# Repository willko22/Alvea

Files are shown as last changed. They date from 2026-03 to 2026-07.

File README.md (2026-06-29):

# ⬡ Alvea

**Wireless split keyboard · nRF52840 · ZMK · hexagonal keycaps**

A low-power, battery-powered wireless split keyboard. Each half is a fully independent BLE device with its own battery, per-key LEDs, and USB-C charging.






> [!WARNING]
> **Work in progress — nothing here has been fabricated or tested yet.**
> The hardware is fully designed, but the boards haven't been manufactured, assembled, or brought up. Any performance numbers are design targets, not measurements, and the firmware doesn't exist yet. This repo is documentation of my hobby build, not a guide for replicating it.

---

## 🗺️ Roadmap

| Stage | Status |
|---|---|
| Schematic design | ✅ Done |
| PCB layout | ✅ Done |
| BOM finalized | ✅ Done |
| **PCB polishing + panelization** | 🔄 **In progress** |
| PCB fabrication (JLCPCB) | ⬜ Planned |
| SMT assembly | ⬜ Planned |
| Hand-soldering (sockets, LEDs, battery lead) | ⬜ Planned |
| Bootloader flashing (SWD, one-time) | ⬜ Planned |
| ZMK firmware (keymap + board definition) | ⬜ Not started |
| Bring-up & testing | ⬜ Planned |
| 3D-printed case | ⬜ Planned (after electronics work) |
| Renders / photos | ⬜ Not yet available |

**Right now:** finishing the PCBs and panelizing for fabrication.
**After that:** fabrication → SMT assembly → hand-soldering → firmware → testing → case design.

Legend: ✅ done · 🔄 in progress · ⬜ planned / not started

---

## ✨ Highlights

- **Wireless BLE** — each half is fully independent; no TRRS cable between halves
- **nRF52840 module (Ebyte E73-2G4M08S1C)** — integrated PCB antenna, so no RF design needed
- **ZMK firmware** *(planned)* — flexible keymaps, deep-sleep power management, drag-and-drop USB updates
- **19 functional keys per half** in a 5×4 matrix, plus a dedicated power switch
- **Per-key LEDs** shining up through translucent hexagonal HEX keycaps
- **USB-C charging** with a dedicated fuel gauge for accurate battery reporting
- **Single 3.5 Ah LiPo per half** with ZMK deep sleep — see [`DESIGN.md`](DESIGN.md) for the per-component power breakdown

Full technical detail — every component, net, pin assignment, BOM line, the power/charging architecture, and the design rationale — lives in [`DESIGN.md`](DESIGN.md).

---

## 🛒 Sourcing

| Source | Parts |
|---|---|
| [JLCPCB](https://jlcpcb.com/) | PCB fabrication + SMT assembly of the small components |
| [Keeb Supply](https://keeb.supply/) | Twilight low-profile switches, HEX keycaps, foam Choc spacers, hotswap Choc sockets, battery connector |
| [TME](https://www.tme.eu/) | Per-key LEDs, battery, and a Raspberry Pi Pico (firmware burner + SWD debugger) |

The switches are **not soldered** — only the hotswap Choc sockets are, and the switches snap into those.

---

## 📄 License

This repository is **split-licensed**:

- **Hardware design files & documentation** — [CC BY-NC 4.0](https://creativecommons.org/licenses/by-nc/4.0/). Use, share, and modify freely with credit, but **not for commercial purposes** — no one may sell Alvea or its derivatives without my explicit consent. See [`LICENSE`](LICENSE).
- **Firmware** (ZMK keymap / board definition) — [MIT](https://opensource.org/licenses/MIT), matching [ZMK](https://zmk.dev/)'s own license so it stays compatible with the ZMK ecosystem. See [`LICENSE-FIRMWARE`](LICENSE-FIRMWARE).

The non-commercial restriction protects the hardware — the part someone would actually manufacture. The firmware is a thin config on top of MIT-licensed ZMK, so it matches ZMK.

---

## 🙏 Acknowledgements

- [ZMK Firmware](https://zmk.dev/)
- [Adafruit nRF52 Bootloader](https://github.com/adafruit/Adafruit_nRF52_Bootloader)
- [fkcaps HEX keycaps](https://fkcaps.com/keycaps/hex) by *s-ol*
- The KiCad community for guidance

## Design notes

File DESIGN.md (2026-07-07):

# Alvea — nRF52840 Wireless Split Keyboard Design Summary

## Overview

- **MCU module:** Ebyte **E73-2G4M08S1C** (U2, `C356849`) — pre-certified nRF52840 module with **integrated PCB antenna**, 32 MHz crystal, RF matching, and DC-DC inductors all internal. Chosen on KiCad-community advice to avoid hand-designing an RF/antenna section.
- **Type:** Wireless split keyboard — both halves are identical component-wise, each half fully independent.
- **Firmware:** ZMK
- **Bootloader:** Adafruit nRF52 UF2 bootloader (flashed via SWD once)
- **Power:** LiPo 3.5 Ah (3500 mAh) single cell
- **Key switches:** Ambient Silent Twilight (Choc low-profile, silent linear), HEX footprint
- **Keycaps:** fkcaps HEX — hexagonal, translucent ABS (RGB-friendly); requires HEX-footprint PCB
- **Keys:** 20 switches per half = **19 functional matrix keys + 1 dedicated power switch (S20, outside the matrix)**
- **Matrix:** 5 columns × 4 rows (19 of 20 positions populated with diodes D2–D20)
- **PCB:** Designed in KiCad, manufactured by JLCPCB
- **Assembly:** JLCPCB SMT for small components; hotswap sockets, per-key LEDs, and battery lead hand-soldered. Switches snap into the hotswap sockets (not soldered). Foam Choc spacers sit under the switches to lower typing volume.

---

## What Changed vs. Previous Revision (discrete-nRF design)

- **Bare nRF52840-QIAA → E73-2G4M08S1C module.** Removed from the board (now internal to module): 32 MHz HF crystal X1, RF matching L1/C3/C4, PCB trace antenna, DCDC inductors L2/L4, and the bulk of MCU decoupling.
- **Battery monitoring: resistor-divider ADC → dedicated fuel gauge.** Added **MAX17048 (U8, `C2682616`)** on the I2C bus with an alert line. Removed the old P0.29/AIN5 resistor divider (the previous revision's battery-sense pair) and all ZMK ADC-gain notes. *(Note: the R2/R3 designators are reused in this revision for unrelated parts — see BOM.)*
- **Added USB ESD protection: USBLC6-2SC6 (U9)** on D+/D−.
- **Power-circuit ICs renumbered & re-specified** (Schmitt, D-FF, charger, protection — see below).
- **LED driver unchanged in concept: still LP5024 over I²C.**
- **LDO and all discrete RF parts: dropped / absorbed into module.**

---

## PCB Architecture — Two Board Design

- **Module board:** E73 module, LP5024, MAX17048, BL8573 charger, DW01A protection, power-switch latch circuit, USB-C, USB ESD diode, battery header, all passives
- **Matrix board:** Key switches (DNP), hotswap sockets (DNP), diodes (JLCPCB populated), per-key LEDs (DNP, hand soldered)
- **Connection:** FPC flat flexible cable (pin count per layout)

---

## Power Architecture

- **VBUS_RAW:** Raw USB-C 5 V → polyfuse F1 → VBUS net
- **VBUS:** Feeds charger (U5) and module USB/VBUS-sense (U2 pad 27)
- **BAT+:** LiPo positive, switched via P-MOS Q1
- **PWR net:** Switched BAT+ output (drain of Q1) — powers the module (Vin), LP5024 VCC, and all LED anodes
- **VDD_NRF:** Regulated rail **out of the module** (module pad 19); used as the local logic reference / I²C pull-up rail
- **GND:** BAT− to GND plane always

---

## Power Consumption (per half)

All figures are typical design-reference values, **not measured** — nothing has been fabricated or profiled yet. Actual draw depends on ZMK configuration, BLE connection interval, and LED usage.

### Battery
- **Cell:** single LiPo, 3500 mAh (3.5 Ah) nominal, ~3.7 V

### Per-LED
- **Per LED:** ~1 mA (OSO5PAS1C1A-1MA, driven by LP5024 constant-current sink)
- **All 19–20 LEDs at full brightness:** ~20 mA total
- LED current is set by the LP5024 (RIREF = R6, 75.3 kΩ), independent of MCU draw
- LEDs are off when LED_EN (module pad 15) is LOW; LP5024 shutdown draw ~1 µA

### MCU (nRF52840 module, E73-2G4M08S1C)
- **Deep sleep (System OFF / ZMK deep sleep):** ~single-digit µA for a cleanly configured board (peripherals disabled, no leaky external circuits)
- **Active, BLE connected (idle-to-typing):** typically ~hundreds of µA up to low single-digit mA, varying with BLE connection interval and scan rate
- **BLE TX bursts:** transient peaks higher than the average active figure

### Always-on support circuitry
- **MAX17048 fuel gauge:** ~3 µA (hibernate) typical — confirm against datasheet
- **LP5024 (enabled, outputs off):** quiescent draw per datasheet; ~1 µA in shutdown when LED_EN is LOW
- **Power-latch logic (Schmitt + D-FF) and protection/charger ICs:** small quiescent draws contributing to standby current

### Dominant draw
- The **LEDs dominate** active consumption by a wide margin: ~20 mA with all LEDs on vs. single-digit µA asleep and sub-mA for the MCU when typing. LED duty cycle is therefore the single largest factor in overall draw.

---

## Power Switch / Latch Circuit (same topology, new refs)

- **P-MOS:** Q1 — `C389353` (Nexperia PMF170XP,115, SOT-323)
  - Gate = PMOS_GATE (from D-flip-flop), Source = BAT+, Drain = PWR
- **Power button:** SW (S20) — BAT+ → PWR_BTN net (separate from the key matrix)
- **Schmitt trigger:** U1 — **SN74LVC1G17 (`C7836`)**, SOT-23-5 (was 74AHC1G14)
  - RC long-press timing on PWR_BTN
- **D-flip-flop:** U3 — **SN74LVC1G74 (`C2870716`)**, X2SON-8 (was 74HC dual)
  - Toggles PMOS_GATE on a valid long press
- **Power-button sense:** **PWR_BTN_PRESS** net → module pad 6, via R1/R2 divider — lets the MCU detect button presses for other functions while powered on.
- **Discharge/steering diode:** D1 — `C94366` (onsemi NSR05F20, Schottky 0402)
- **Pull-down:** R3 — `C25744` (10 kΩ)

---

## Battery Charger — BL8573

- **IC:** U5 — `C2999147` (BL8573CS8TR, ESOP-8)
- **VCC:** VBUS (5 V), **BAT:** BAT+
- **Charge current: 1.47 A** (R11 = 680 Ω). Per BL8573 datasheet V1.2: ICHG = (VPROG / RPROG) × 1000, VPROG = 1 V → 1000 / 680 ≈ 1.47 A (~0.42C into the 3.5 Ah cell).
- **RPROG:** R11 — `C137948` (680 Ω).
- Requires a ≥1.5 A USB source for full current; a 500 mA port current-limits lower.
- Dissipation at 1.47 A: P_D ≈ (5 V − 3.75 V) × 1.47 A ≈ 1.84 W in the ESOP-8. U5 uses a wide GND pour + thermal vias; thermal regulation throttles ICHG above ~120 °C die temp.
- RPROG sets battery charge current only — independent of LED current (LP5024 controls that, ~1 mA/LED).
- **CHRG:** open-drain → STDBY/CHRG nets → module (CHRG = pad 4, STDBY = pad 3) as GPIO status inputs
- **Polyfuse:** F1 — `C2760275` (SMD1206-150C-16V) between VBUS_RAW and VBUS
- Logic: CHRG LOW = charging, STDBY LOW = charge complete

---

## Battery Protection — DW01A + Dual MOSFET

- **IC:** U6 — `C42380662` (DW01A, SOT-23-6)
- **MOSFET:** Q2 — `C2830320` (FS8205A dual N-MOS, SOT-23-6)
- Standard 1-cell Li-ion protection (overcharge / overdischarge / overcurrent)
- Nets: U6 OD/OC → Q2 G2/G1; sense node U6-VM; pack negative to GND

---

## Battery Fuel Gauge — MAX17048 (NEW)

- **IC:** U8 — `C2682616` (MAX17048, DFN-8 2×2 mm)
- **Function:** I²C state-of-charge / cell-voltage gauge — replaces the old resistor-divider + nRF ADC scheme
- **VCC/CELL:** BAT+ (pins 2/3), **GND:** pins 1/4/6/9
- **SCL:** pin 7 → SCL bus, **SDA:** pin 8 → SDA bus
- **ALRT (BAT_ALTR):** pin 5 → module pad 9, pulled via R4 — wake/alert on low charge
- ZMK: use a fuel-gauge battery driver over I²C (not the ADC voltage-divider sensor)

---

## I²C Bus (shared)

- **Members:** Module U2 (SDA pad 7 / SCL pad 8), LP5024 U7 (SDA pin 28 / SCL pin 29), MAX17048 U8 (SDA pin 8 / SCL pin 7)
- **Pull-ups:** SDA → R14, SCL → R16 (both `C25905`, 5.1 kΩ) to VDD_NRF

---

## Battery Connector

- **2-pin header, hand-soldered** (not in BOM by design). Pin 1 = BAT+, Pin 2 = GND. Mates with the LiPo JST lead.
- A 3-pin TH header **H1 (`C22373927`)** is the **debug header: SWDIO, SWDCLK, GND** — for one-time bootloader flashing via the Pico programmer. Distinct from the hand-soldered 2-pin battery lead.

---

## USB-C + ESD

- **Connector:** USBC1 — `C165948` (TYPE-C-31-M-12, right-angle SMD)
- **VBUS_RAW** (A4/B9 + B4/A9) → F1 → VBUS; **GND** to GND
- **D+/D−:** through **USBLC6-2SC6 (U9)** ESD array → module D+/D− (pads 31 / 29)
- **CC1/CC2:** 5.1 kΩ to GND (sink/UFP)
- **Decoupling:** C5 (`C703694`, 4.7 µF) on VBUS

---

## E73 Module Core

- nRF52840 + 32 MHz crystal + RF matching + integrated antenna, all internal — no external RF parts on the board.
- **LF crystal (32.768 kHz):** X1 — `C99010` (FC-135 9 pF ±20 ppm) external, for accurate low-power RTC/sleep timing. Load caps C1/C3 (`C1547`, 12 pF C0G).
- **VDD_NRF:** module-regulated logic rail out (pad 19).
- **PWR (Vin):** pad 23, from switched BAT+.
- **Module decoupling:** C2/C7/C8 (`C52923`, 1 µF) and C4/C6/C9 (`C307331`, 100 nF) on PWR/VDD_NRF/RESET.

---

## LP5024 LED Driver

- **IC:** U7 — `C427525` (TI LP5024, VQFN-32 4×4 mm, constant-current sink) over **I²C**
- **VCC (pin 27):** PWR (switched BAT+)
- **VCAP (pin 32):** 1 µF to GND; **VLED:** LED anodes tied directly to PWR
- **SCL/SDA:** shared I²C bus (pins 29 / 28)
- **EN (LED_EN, pin 30):** module pad 15 + pull-down R17 (`C26083`, 1 MΩ) — GPIO HIGH = on, LOW/deep-sleep = ~1 µA shutdown
- **RIREF:** R6 (`C491105`, 75.3 kΩ ERA2AED753X) → sets per-channel max current
- **OUT0–OUT19 → LED1…LED20** (19 per-key LEDs used + spare); OUT20–23 unused
- **Flow:** PWR → LED anode → cathode → LP5024 OUTx → GND
- **Brightness:** I²C BANK_BRIGHTNESS (single write drives all keys)

---

## Per-Key LEDs

- **Part:** 20× OPTOSUPPLY **OSO5PAS1C1A-1MA** (Orange 3528/PLCC2, Vf 1.5–2.2 V, 1 mA, 120° viewing)
- **Source:** Local supplier (not LCSC) — **hand soldered** after PCB arrives
- **Schematic:** DNP placeholder, 3528 footprint
- **Connection:** Anode → PWR, Cathode → LP5024 OUTx
- **Total current:** ~20 mA

---

## Key Matrix

- **Layout:** 5 columns × 4 rows; **19 functional keys** (diodes D2–D20) + S20 power switch outside the matrix
- **Switches:** Ambient Silent Twilight Choc low-profile (HEX footprint), hotswap (DNP)
- **Diodes:** D2–D20 — `C6341459` (CDSQC4148-HF, DFN1006) one per switch
- **Orientation / scan:** row2col — `diode-direction = "row2col"`; rows driven, columns read
- **Anti-ghosting:** diode on every switch

### Matrix nets (from netlist)
- **ROWs → module:** ROW1 pad 10, ROW2 pad 12, ROW3 pad 28, ROW4 pad 43
- **COLs → module:** COL1 pad 40, COL2 pad 38, COL3 pad 36, COL4 pad 34, COL5 pad 32
- Each ROW drives the anodes of 5 (ROW1–3) or 4 (ROW4) diodes → switch → COL.

---

## GPIO / Module-Pad Assignments

Net → E73 module pad. Raw nRF pins are shown where the layout data embeds them.

| Net | Module pad | nRF (if known) |
|-----|---|---|
| ROW1 | 10 | — |
| ROW2 | 12 | — |
| ROW3 | 28 | — |
| ROW4 | 43 | — |
| COL1 | 40 | — |
| COL2 | 38 | — |
| COL3 | 36 | — |
| COL4 | 34 | — |
| COL5 | 32 | — |
| SDA (I²C) | 7 | — |
| SCL (I²C) | 8 | — |
| LED_EN | 15 | — |
| PWR_BTN_PRESS | 6 | — |
| BAT_ALTR (gauge ALRT) | 9 | — |
| CHRG (charger status) | 4 | — |
| STDBY (charger status) | 3 | — |
| RESET | 26 | P0.18/RESET |
| USB D+ | 31 | — |
| USB D− | 29 | — |
| VBUS sense | 27 | — |
| SWDIO | 37 | — |
| SWDCLK | 39 | — |
| VDD_NRF (out) | 19 | — |
| PWR (Vin) | 23 | — |

> Note: the layout file also exposes several module pads carrying raw nRF labels (P1.11, P1.10, P0.06, P0.08, P1.09, P0.07, P0.13, P0.24, P1.06) that are routed to internal/spare nets — available for future use.

---

## SWD

- Debug header **H1** (3-pin TH, `C22373927`): SWDIO (pad 37), SWDCLK (pad 39), GND
- Programmer: Raspberry Pi Pico + picoprobe
- Use: flash Adafruit nRF52 UF2 bootloader once; thereafter ZMK via USB drag-and-drop

---

## Reset

- **SW1** — `C720477` (TS-1088-AR02016 tactile) → RESET net (module pad 26)
- Debounce: C6 (`C307331`, 100 nF) + R8 (`C25744`, 10 kΩ) pull-up

---

## Components Dropped / Absorbed

- **Bare nRF52840-QIAA, 32 MHz crystal, RF matching (L1/C3/C4), trace antenna, DCDC inductors L2/L4** — now inside the E73 module
- **LDO (TPS7A0233)** — no 3V3 loads
- **Resistor-divider battery sense (old AIN5 divider + ADC)** — replaced by MAX17048 *(designators R2/R3 are reused for other parts this revision)*
- **IS31FL3731** — replaced by LP5024 (legacy)
- Series LED resistor — LP5024 sets current

---

## BOM (left half, as built)

| Ref | Value / MPN | LCSC | Notes |
|-----|---|---|---|
| U2 | E73-2G4M08S1C | C356849 | nRF52840 module w/ antenna |
| U7 | LP5024RSMR | C427525 | 24-ch LED driver, I²C |
| U8 | MAX17048 | C2682616 | Fuel gauge, I²C |
| U5 | BL8573CS8TR | C2999147 | Li-ion charger |
| U6 | DW01A | C42380662 | Battery protection |
| U1 | SN74LVC1G17 | C7836 | Schmitt trigger (power latch) |
| U3 | SN74LVC1G74 | C2870716 | D-flip-flop (power latch) |
| U9 | USBLC6-2SC6 | C7519 | USB ESD on D+/D− |
| Q1 | PMF170XP,115 | C389353 | Power-switch P-MOS |
| Q2 | FS8205A | C2830320 | Protection dual N-MOS |
| USBC1 | TYPE-C-31-M-12 | C165948 | USB-C |
| X1 | FC-135 32.768 kHz 9 pF | C99010 | LF crystal |
| L1 | BRC2016 10 µH | C223154 | (board inductor) |
| F1 | SMD1206-150C-16V | C2760275 | Polyfuse |
| H1 | HC-PM254 3P header | C22373927 | debug: SWDIO/SWDCLK/GND |
| D1 | NSR05F20NXT5G | C94366 | Schottky (power ckt) |
| D2–D20 (×19) | CDSQC4148-HF | C6341459 | Matrix diodes |
| C1, C3 | 12 pF C0G | C1547 | LF crystal load |
| C2, C7, C8 | 1 µF | C52923 | decoupling |
| C4, C6, C9 | 100 nF | C307331 | decoupling |
| C5 | 4.7 µF | C703694 | VBUS bulk |
| R1, R17 | 1 MΩ | C26083 | PWR_BTN_PRESS / LED_EN |
| R9, R10, R14, R16 | 5.1 kΩ | C25905 | CC + I²C pull-ups |
| R11 | 680 Ω | C137948 | RPROG → 1.47 A charge current |
| R3, R4, R7, R8, R12, R13 | 10 kΩ | C25744 | R3 = power-btn pull-down; rest = pull-ups / status |
| R2 | 2.49 MΩ | C368359 | timing |
| R5 | 2.61 MΩ | C166493 | RC timing (0402) |
| R6 | 75.3 kΩ | C491105 | LP5024 IREF |
| SW1 | TS-1088-AR02016 | C720477 | Reset button |
| S20 | power switch | — | separate, on BAT+/PWR_BTN |
| LED ×20 | OSO5PAS1C1A-1MA orange | DNP local | hand soldered |
| BATTERY | 3500 mAh LiPo | — | 2-pin lead hand-soldered |
| FI1–3 | fiducials | — | — |

---

## Key Design Decisions

- **Module over discrete RF:** E73-2G4M08S1C — integrated antenna removes RF/antenna design risk (KiCad-community recommendation)
- **Fuel gauge over ADC divider:** MAX17048 for accurate SoC reporting
- **LED:** 19–20× orange 3528 @ ~1 mA driven by LP5024 over I²C, anodes to PWR
- **I²C bus:** module + LP5024 + MAX17048, 5.1 kΩ pull-ups to VDD_NRF
- **Power latch:** long-press Schmitt + D-FF toggles P-MOS; MCU also senses press via PWR_BTN_PRESS
- **Matrix:** row2col, 5×4, 19 functional + 1 power switch
- **Split:** wireless BLE, identical halves, each independent
- **SWD:** one-time bootloader flash via Pico, then USB UF2

---

## Notes

- **Charge current** is 1.47 A (R11 = 680 Ω), verified against BL8573 datasheet V1.2. Use a ≥1.5 A USB source for full current.
- **GPIO table** lists net → E73 module pad. Raw nRF `Px.yy` names are only needed if a ZMK config requires them; the module's pad / Pro-Micro-style mapping is normally sufficient.

---

## Sourcing

| Source | Parts |
|---|---|
| JLCPCB | PCB fabrication + SMT assembly of the small components |
| Keeb Supply | Twilight low-profile switches, HEX keycaps, foam Choc spacers, hotswap Choc sockets, battery connector |
| TME | Per-key LEDs, battery, and a Raspberry Pi Pico (firmware burner + SWD debugger) |

Switches are not soldered — only the hotswap Choc sockets are, and the switches snap into those.

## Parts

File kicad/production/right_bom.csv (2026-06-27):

Designator | Footprint | Quantity | Value | LCSC Part #
C1, C3 | C0402 | 2 | 0402CG120F500NT | C182477
C10, C13 | C0402 | 2 | CL05B104KB54PNC | C307331
C5 | C0402 | 1 | ZRB15XR61A475KE01D | C703694
C6 | C0201 | 1 | GRM033C71C104KE14D | C85923
C7, C8, C9 | C0402 | 3 | CL05A105KA5NQNC | C52923
D1 | DSN2_L1.0-W0.6-RD | 1 | NSR05F20NXT5G | C94366
F1 | F1206 | 1 | SMD1206-150C-16V | C2760275
FI6 |  | 1 | Fiducial_1mm_Mask2mm
Q1 | SOT-323-3_L2.0-W1.3-P1.30-LS2.1-BR | 1 | PMF170XP,115 | C389353
Q2 | SOT-23-6_L2.9-W1.6-P0.95-LS2.8-BR | 1 | FS8205A_C2830320 | C2830320
R1 | R0402 | 1 | RC0402FR-071ML | C138033
R10, R14, R16, R9 | R0402 | 4 | 0402WGF5101TCE | C25905
R11 | R0402 | 1 | RC0402FR-07680RL | C137948
R13, R15, R18, R19 | R0402 | 4 | 0402WGF1002TCE | C25744
R17 | R0402 | 1 | 0402WGF1004TCE | C26083
R2 | R0402 | 1 | WR04W2494FTL | C368359
R5 | R0402 | 1 | RC0402FR-07100KL | C60491
R6 | R0402 | 1 | ERA2AED753X | C491105
R7 | R0402 | 1 | RTT022614FTH | C166493
R8 | R0402 | 1 | RC0402FR-0710KL | C60490
SW1 | SW-SMD_L3.9-W3.0-P4.45 | 1 | TS-1088-AR02016 | C720477
U1 | SOT-23-5_L3.0-W1.7-P0.95-LS2.8-BR | 1 | SN74LVC1G17DBVR | C7836
U5 | ESOP-8_L4.9-W3.9-P1.27-LS6.0-BL-EP | 1 | BL8573CS8TR | C2999147
U8 | DFN-8_2x2mm_P0.5mm_EP1.2x0.8mm | 1 | MAX17048 | C2682616
U9 | SOT-23-6 | 1 | USBLC6-2SC6
USBC1 | USB-C_SMD-TYPE-C-31-M-12_1 | 1 | TYPE-C-31-M-12 | C165948
X1 | OSC-SMD_L3.2-W1.5 | 1 | FC-13532.768KHZ9PF20PPM | C99010

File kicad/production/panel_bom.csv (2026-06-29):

Designator | Footprint | Quantity | Value | LCSC Part #
C1_2, C3_2 | C0402 | 2 | 0402CG120J500NT | C1547
C1, C3 | C0402 | 2 | 0402CG120F500NT | C182477
C10, C13, C4, C6_2, C6, C9_2 | C0402 | 6 | CL05B104KB54PNC | C307331
C2, C7_2, C7, C8_2, C8, C9 | C0402 | 6 | CL05A105KA5NQNC | C52923
C5_2, C5 | C0402 | 2 | ZRB15XR61A475KE01D | C703694
D1_2, D1 | DSN2_L1.0-W0.6-RD | 2 | NSR05F20NXT5G | C94366
D10_2, D10, D11_2, D11, D12_2, D12, D13_2, D13, D14_2, D14, D15_2, D15, D16_2, D16, D17_2, D17, D18_2, D18, D19_2, D19, D2_2, D2, D20_2, D20, D3_2, D3, D4_2, D4, D5_2, D5, D6_2, D6, D7_2, D7, D8_2, D8, D9_2, D9 | X1-DFN1006-2_L1.0-W0.6-RD | 38 | CDSQC4148-HF | C6341459
F1_2, F1 | F1206 | 2 | SMD1206-150C-16V | C2760275
FI1, FI2, FI3, FI6 |  | 4 | Fiducial_1mm_Mask2mm
H1_2 | HDR-TH_3P-P2.54_HC-PM254-8.5H-1X3PW | 1 | HC-PM254-8.5H-1X3PW | C22373927
L1_2 | IND-SMD_L2.0-W1.6_BRC2016 | 1 | BRC2016T100K | C223154
Q1_2, Q1 | SOT-323-3_L2.0-W1.3-P1.30-LS2.1-BR | 2 | PMF170XP,115 | C389353
Q2_2, Q2 | SOT-23-6_L2.9-W1.6-P0.95-LS2.8-BR | 2 | FS8205A_C2830320 | C2830320
R1_2, R1, R17_2, R17 | R0402 | 4 | 0402WGF1004TCE | C26083
R10_2, R10, R14_2, R14, R16_2, R16, R9_2, R9 | R0402 | 8 | 0402WGF5101TCE | C25905
R11_2, R11 | R0402 | 2 | RC0402FR-07680RL | C137948
R12, R13_2, R13, R15, R18, R19, R3, R4, R5, R7_2, R8_2, R8 | R0402 | 12 | 0402WGF1002TCE | C25744
R2_2, R2 | R0402 | 2 | WR04W2494FTL | C368359
R5_2, R7 | R0402 | 2 | RTT022614FTH | C166493
R6_2, R6 | R0402 | 2 | ERA2AED753X | C491105
SW1_2, SW1 | SW-SMD_L3.9-W3.0-P4.45 | 2 | TS-1088-AR02016 | C720477
U1_2, U1 | SOT-23-5_L3.0-W1.7-P0.95-LS2.8-BR | 2 | SN74LVC1G17DBVR | C7836
U10 | X2SON-8_L1.4-W1.0-P0.35-BL | 1 | SN74LVC1G74DQER | C2870716
U2_2 | WIRELM-SMD_E73-2G4M08S1C | 1 | E73-2G4M08S1C | C356849
U4_2 | CONN-TH_S2B-PH-K-S-LF-SN | 1 | S2B-PH-K-S(LF)(SN) | C173752
U5_2, U5 | ESOP-8_L4.9-W3.9-P1.27-LS6.0-BL-EP | 2 | BL8573CS8TR | C2999147
U6_2 | SOT-23-6_L2.9-W1.6-P0.95-LS2.9-BL | 1 | DW01A_C42380662 | C42380662
U7_2 | VQFN-32_L4.0-W4.0-P0.40-TL-EP | 1 | LP5024RSMR | C427525
U8_2, U8 | DFN-8_2x2mm_P0.5mm_EP1.2x0.8mm | 2 | MAX17048 | C2682616
U9_2, U9 | SOT-23-6 | 2 | USBLC6-2SC6
USBC1_2, USBC1 | USB-C_SMD-TYPE-C-31-M-12_1 | 2 | TYPE-C-31-M-12 | C165948
X1_2, X1 | OSC-SMD_L3.2-W1.5 | 2 | FC-13532.768KHZ9PF20PPM | C99010

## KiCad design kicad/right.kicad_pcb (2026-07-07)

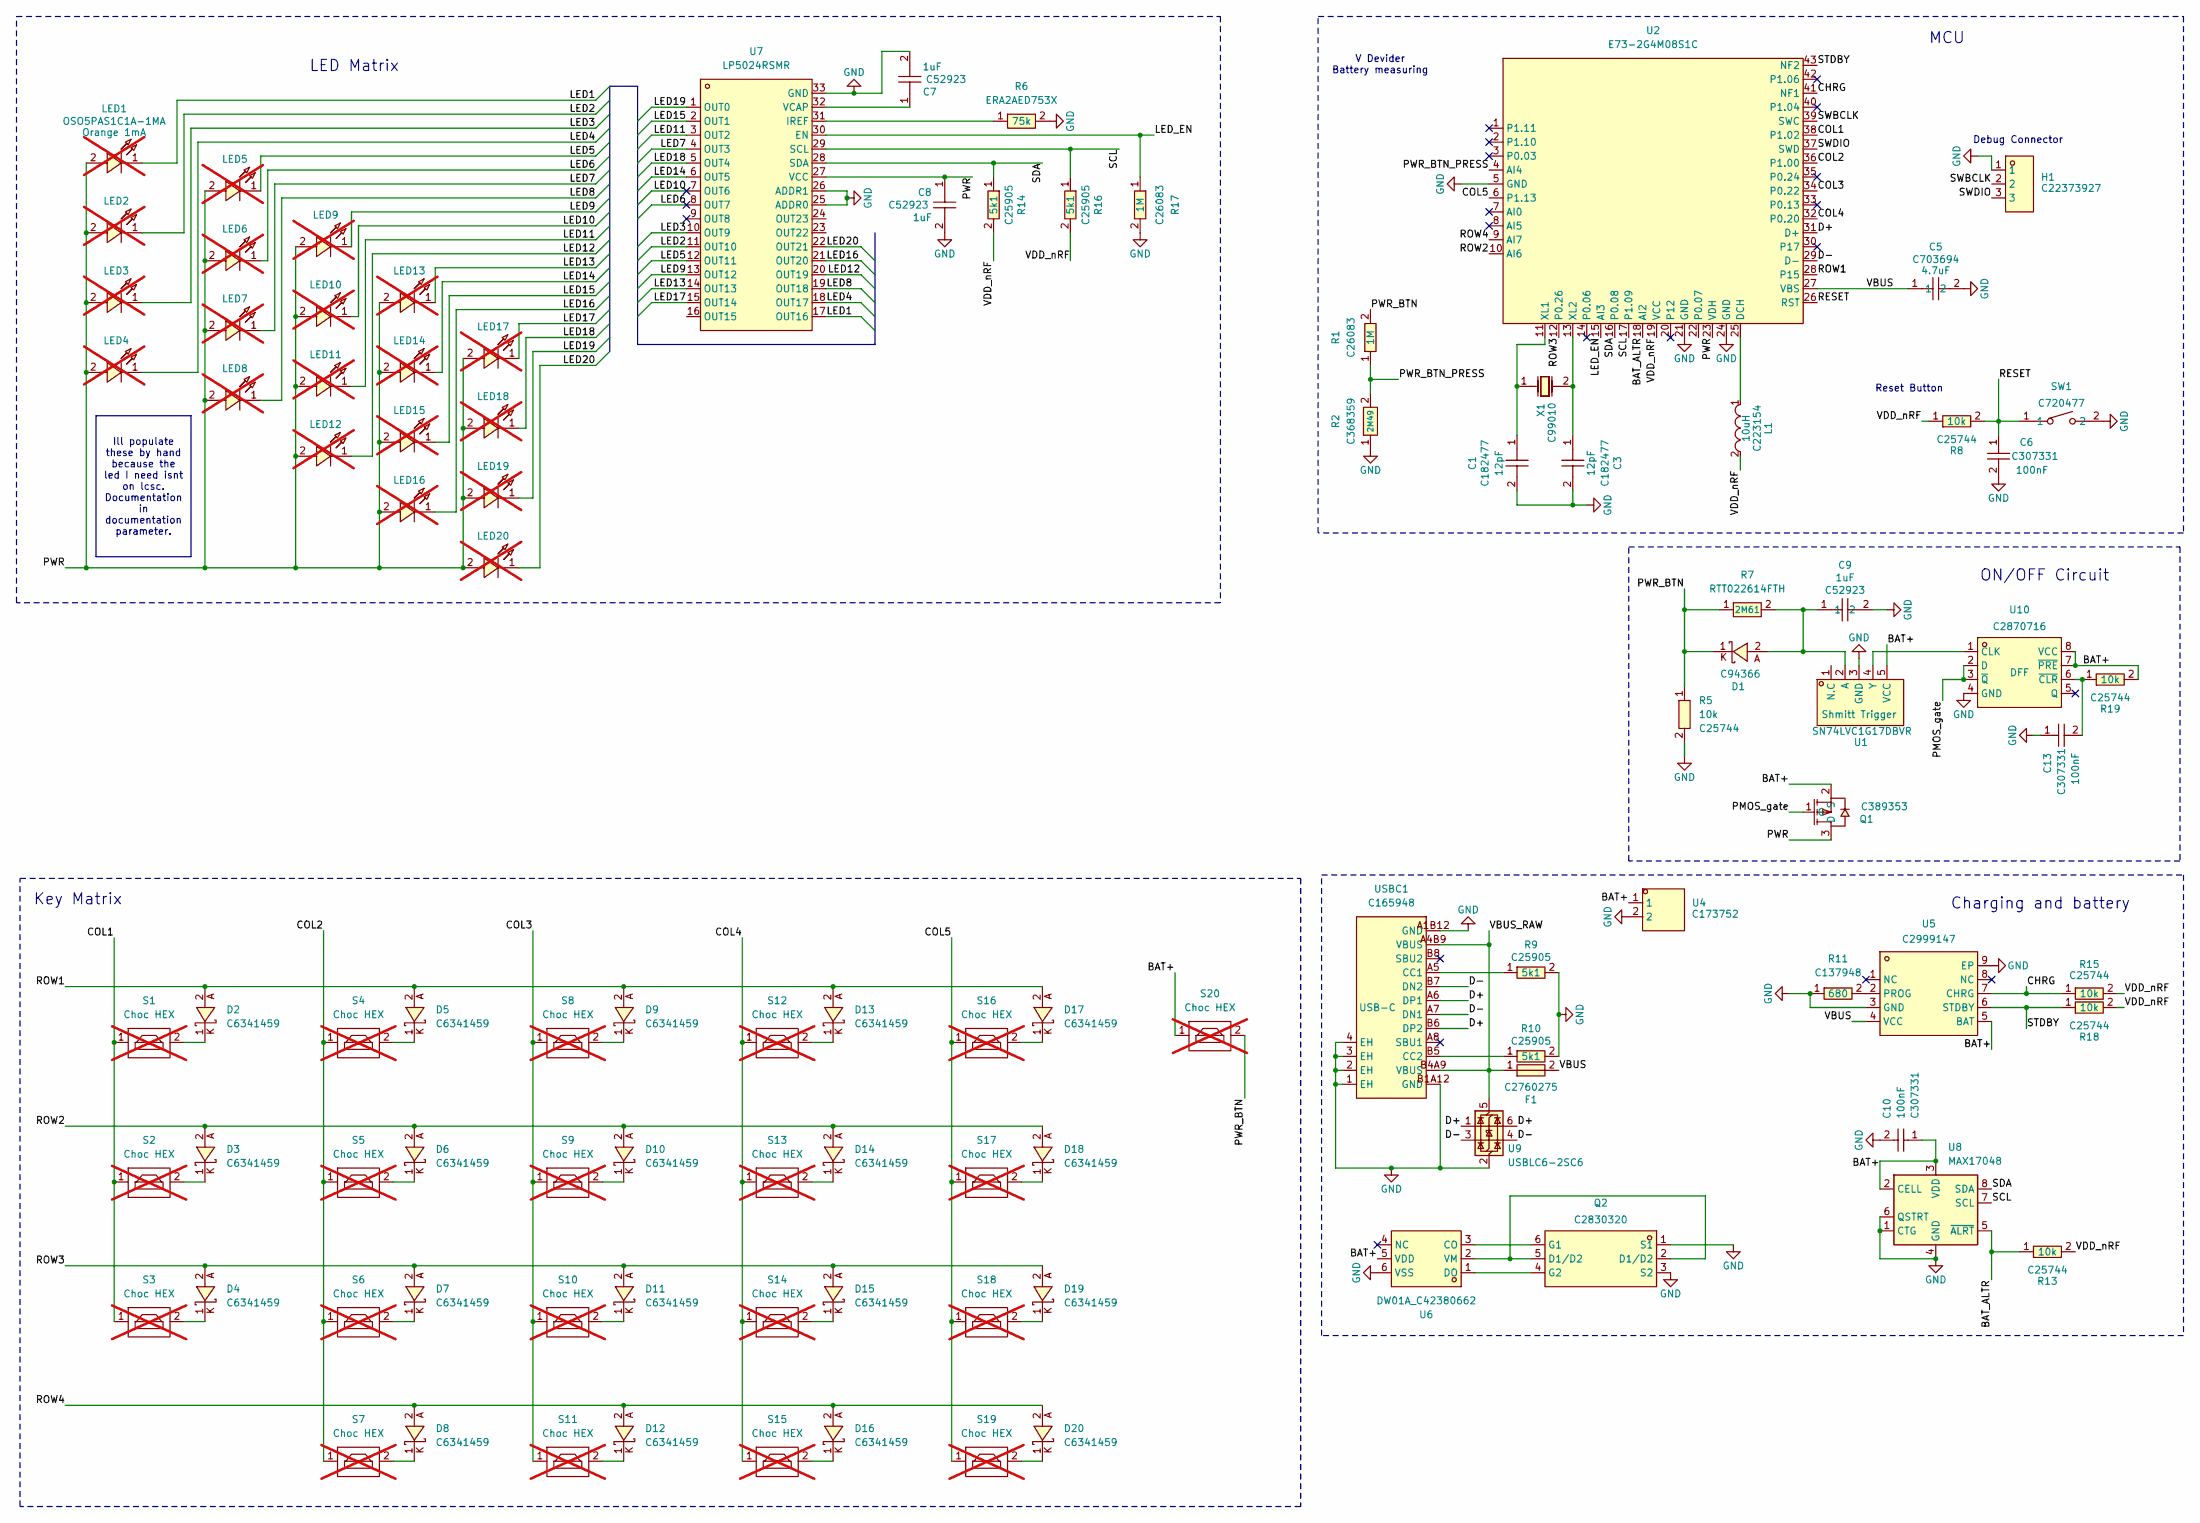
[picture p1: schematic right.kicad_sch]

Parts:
C1, C3: 0402CG120F500NT; C0402; LCSC Part C182477
C5: ZRB15XR61A475KE01D; C0402; MPN ZRB15XR61A475KE01D; LCSC Part C703694
C6, C10, C13: CL05B104KB54PNC; C0402; LCSC Part C307331
C7, C8, C9: CL05A105KA5NQNC; C0402; LCSC Part C52923
D1: NSR05F20NXT5G; DSN2_L1.0-W0.6-RD; LCSC Part C94366
D2, D3, D4, D5, D6, D7, D8, D9, D10, D11, D12, D13, D14, D15, D16, D17, D18, D19, D20: CDSQC4148-HF; X1-DFN1006-2_L1.0-W0.6-RD; LCSC Part C6341459
F1: SMD1206-150C-16V; F1206; LCSC Part C2760275
H1: HC-PM254-8.5H-1X3PW; HDR-TH_3P-P2.54_HC-PM254-8.5H-1X3PW; LCSC Part C22373927
L1: BRC2016T100K; IND-SMD_L2.0-W1.6_BRC2016; LCSC Part C223154
LED1, LED2, LED3, LED4, LED5, LED6, LED7, LED8, LED9, LED10, LED11, LED12, LED13, LED14, LED15, LED16, LED17, LED18, LED19, LED20: OSO5PAS1C1A-1MA; LED-SMD_L3.2-W2.8-LS3.5-RD-BLUE; LCSC Part OSO5PAS1C1A-1MA -> on tme.ue; not fitted
Q1: PMF170XP,115; SOT-323-3_L2.0-W1.3-P1.30-LS2.1-BR; LCSC Part C389353
Q2: FS8205A_C2830320; SOT-23-6_L2.9-W1.6-P0.95-LS2.8-BR; LCSC Part C2830320
R1, R17: 0402WGF1004TCE; R0402; LCSC Part C26083
R2: WR04W2494FTL; R0402; LCSC Part C368359
R5, R8, R13, R15, R18, R19: 0402WGF1002TCE; R0402; LCSC Part C25744
R6: ERA2AED753X; R0402; MPN ERA2AED753X; LCSC Part C491105
R7: RTT022614FTH; R0402; MPN RTT022614FTH; LCSC Part C166493
R9, R10, R14, R16: 0402WGF5101TCE; R0402; LCSC Part C25905
R11: RC0402FR-07680RL; R0402; LCSC Part C137948
S1, S2, S3, S4, S5, S6, S7, S8, S9, S10, S11, S12, S13, S14, S15, S16, S17, S18, S19, S20: Choc HEX; PG1350_hotswap; not fitted
SW1: TS-1088-AR02016; SW-SMD_L3.9-W3.0-P4.45; LCSC Part C720477
U1: SN74LVC1G17DBVR; SOT-23-5_L3.0-W1.7-P0.95-LS2.8-BR; MPN SN74LVC1G17DBVR; LCSC Part C7836
U2: E73-2G4M08S1C; WIRELM-SMD_E73-2G4M08S1C; LCSC Part C356849
U4: S2B-PH-K-S(LF)(SN); CONN-TH_S2B-PH-K-S-LF-SN; LCSC Part C173752
U5: BL8573CS8TR; ESOP-8_L4.9-W3.9-P1.27-LS6.0-BL-EP; LCSC Part C2999147
U6: DW01A_C42380662; SOT-23-6_L2.9-W1.6-P0.95-LS2.9-BL; LCSC Part C42380662
U7: LP5024RSMR; VQFN-32_L4.0-W4.0-P0.40-TL-EP; LCSC Part C427525
U8: MAX17048; DFN-8_2x2mm_P0.5mm_EP1.2x0.8mm; LCSC Part C2682616
U9: USBLC6-2SC6; SOT-23-6
U10: SN74LVC1G74DQER; X2SON-8_L1.4-W1.0-P0.35-BL; LCSC Part C2870716
USBC1: TYPE-C-31-M-12; USB-C_SMD-TYPE-C-31-M-12_1; LCSC Part C165948
X1: FC-13532.768KHZ9PF20PPM; OSC-SMD_L3.2-W1.5; LCSC Part C99010

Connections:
/BAT+: C10.1, Q1.2 (S), R19.2, S20.1, U1.5 (VCC), U4.1, U5.5 (BAT), U6.5 (VDD), U8.2 (CELL), U8.3 (VDD), U10.7 (~PRE), U10.8 (VCC); also elsewhere on the board
/BAT_ALTR: R13.1, U2.18 (AI2), U8.5 (~ALRT)
/CHRG: R15.1, U2.41 (NF1), U5.7 (CHRG)
/COL1: S1.1, S2.1, S3.1, U2.38 (P1.02)
/COL2: S4.1, S5.1, S6.1, S7.1, U2.36 (P1.00)
/COL3: S8.1, S9.1, S10.1, S11.1, U2.34 (P0.22)
/COL4: S12.1, S13.1, S14.1, S15.1, U2.32 (P0.20)
/COL5: S16.1, S17.1, S18.1, S19.1, U2.6 (P1.13)
/D+: U2.31 (D+), U9.1 (I/O1), U9.6 (I/O1), USBC1.A6 (DP1), USBC1.B6 (DP2)
/D-: U2.29 (D-), U9.3 (I/O2), U9.4 (I/O2), USBC1.A7 (DN1), USBC1.B7 (DN2)
/LED1: LED1.1, U7.17 (OUT16)
/LED2: LED2.1, U7.11 (OUT10)
/LED3: LED3.1, U7.10 (OUT9)
/LED4: LED4.1, U7.18 (OUT17)
/LED5: LED5.1, U7.12 (OUT11)
/LED6: LED6.1, U7.8 (OUT7)
/LED7: LED7.1, U7.4 (OUT3)
/LED8: LED8.1, U7.19 (OUT18)
/LED9: LED9.1, U7.13 (OUT12)
/LED10: LED10.1, U7.7 (OUT6)
/LED11: LED11.1, U7.3 (OUT2)
/LED12: LED12.1, U7.20 (OUT19)
/LED13: LED13.1, U7.14 (OUT13)
/LED14: LED14.1, U7.6 (OUT5)
/LED15: LED15.1, U7.2 (OUT1)
/LED16: LED16.1, U7.21 (OUT20)
/LED17: LED17.1, U7.15 (OUT14)
/LED18: LED18.1, U7.5 (OUT4)
/LED19: LED19.1, U7.1 (OUT0)
/LED20: LED20.1, U7.22 (OUT21)
/LED_EN: R17.1, U2.15 (AI3), U7.30 (EN)
/PMOS_gate: Q1.1 (G), U10.2 (D), U10.3 (~Q)
/PWR: C8.1, LED1.2, LED2.2, LED3.2, LED4.2, LED5.2, LED6.2, LED7.2, LED8.2, LED9.2, LED10.2, LED11.2, LED12.2, LED13.2, LED14.2, LED15.2, LED16.2, LED17.2, LED18.2, LED19.2, LED20.2, Q1.3 (D), U2.23 (VDH), U7.27 (VCC); also elsewhere on the board
/PWR_BTN: D1.1, R1.2, R5.1, R7.1, S20.2
/PWR_BTN_PRESS: R1.1, R2.2, U2.4 (AI4)
/RESET: C6.1, R8.2, SW1.1, U2.26 (RST)
/ROW1: D2.2, D5.2, D9.2, D13.2, D17.2, U2.28 (P15)
/ROW2: D3.2, D6.2, D10.2, D14.2, D18.2, U2.10 (AI6)
/ROW3: D4.2, D7.2, D11.2, D15.2, D19.2, U2.12 (P0.26)
/ROW4: D8.2, D12.2, D16.2, D20.2, U2.9 (AI7)
/SCL: R16.1, U2.17 (P1.09), U7.29 (SCL), U8.7 (SCL)
/SDA: R14.1, U2.16 (P0.08), U7.28 (SDA), U8.8 (SDA)
/STDBY: R18.1, U2.43 (NF2), U5.6 (STDBY)
/SWBCLK: H1.2, U2.39 (SWC)
/SWDIO: H1.3, U2.37 (SWD)
/VBUS: C5.1, F1.2, U2.27 (VBS), U5.4 (VCC); also elsewhere on the board
/VBUS_RAW: F1.1, U9.5 (VBUS), USBC1.A4B9 (VBUS), USBC1.B4A9 (VBUS)
/VDD_nRF: L1.2, R8.1, R13.2, R14.2, R15.2, R16.2, R18.2, U2.19 (VCC); also elsewhere on the board
GND: C1.2, C3.2, C5.2, C6.2, C7.2, C8.2, C9.2, C10.2, C13.1, H1.1, Q2.1 (S1), Q2.3 (S2), R2.1, R5.2, R6.2, R9.2, R10.2, R11.1, R17.2, SW1.2, U1.3 (GND), U2.5 (GND), U2.21 (GND), U2.24 (GND), U4.2, U5.3 (GND), U5.9 (EP), U6.6 (VSS), U7.25 (ADDR0), U7.26 (ADDR1), U7.33 (GND), U8.1 (CTG), U8.4 (GND), U8.6 (QSTRT), U8.9 (GND), U9.2 (GND), U10.4 (GND), USBC1.1 (EH), USBC1.2 (EH), USBC1.3 (EH), USBC1.4 (EH), USBC1.A1B12 (GND), USBC1.B1A12 (GND); also elsewhere on the board
unnamed: D2.1, S1.2
unnamed: D3.1, S2.2
unnamed: D4.1, S3.2
unnamed: D5.1, S4.2
unnamed: D6.1, S5.2
unnamed: D7.1, S6.2
unnamed: D8.1, S7.2
unnamed: D9.1, S8.2
unnamed: D10.1, S9.2
unnamed: D11.1, S10.2
unnamed: D12.1, S11.2
unnamed: D13.1, S12.2
unnamed: D14.1, S13.2
unnamed: D15.1, S14.2
unnamed: D16.1, S15.2
unnamed: D17.1, S16.2
unnamed: D18.1, S17.2
unnamed: D19.1, S18.2
unnamed: D20.1, S19.2
unnamed: Q2.6 (G1), U6.3 (CO)
unnamed: Q2.4 (G2), U6.1 (DO)
unnamed: C9.1, D1.2, R7.2, U1.2 (A)
unnamed: U1.4 (Y), U10.1 (CLK)
unnamed: L1.1, U2.25 (DCH)
unnamed: C1.1, U2.11 (XL1), X1.1
unnamed: C3.1, U2.13 (XL2), X1.2
unnamed: R11.2, U5.2 (PROG)
unnamed: Q2.2 (D1/D2), Q2.5 (D1/D2), U6.2 (VM)
unnamed: R6.1, U7.31 (IREF)
unnamed: C7.1, U7.32 (VCAP)
unnamed: C13.2, R19.1, U10.6 (~CLR)
unnamed: R9.1, USBC1.A5 (CC1)
unnamed: R10.1, USBC1.B5 (CC2)

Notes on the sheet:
Charging and battery
MCU
Debug Connector
ON/OFF Circuit
Reset Button
Key Matrix
V Devider Battery measuring
LED Matrix
Ill populate these by hand because the led I need isnt on lcsc. Documentation in documentation parameter.

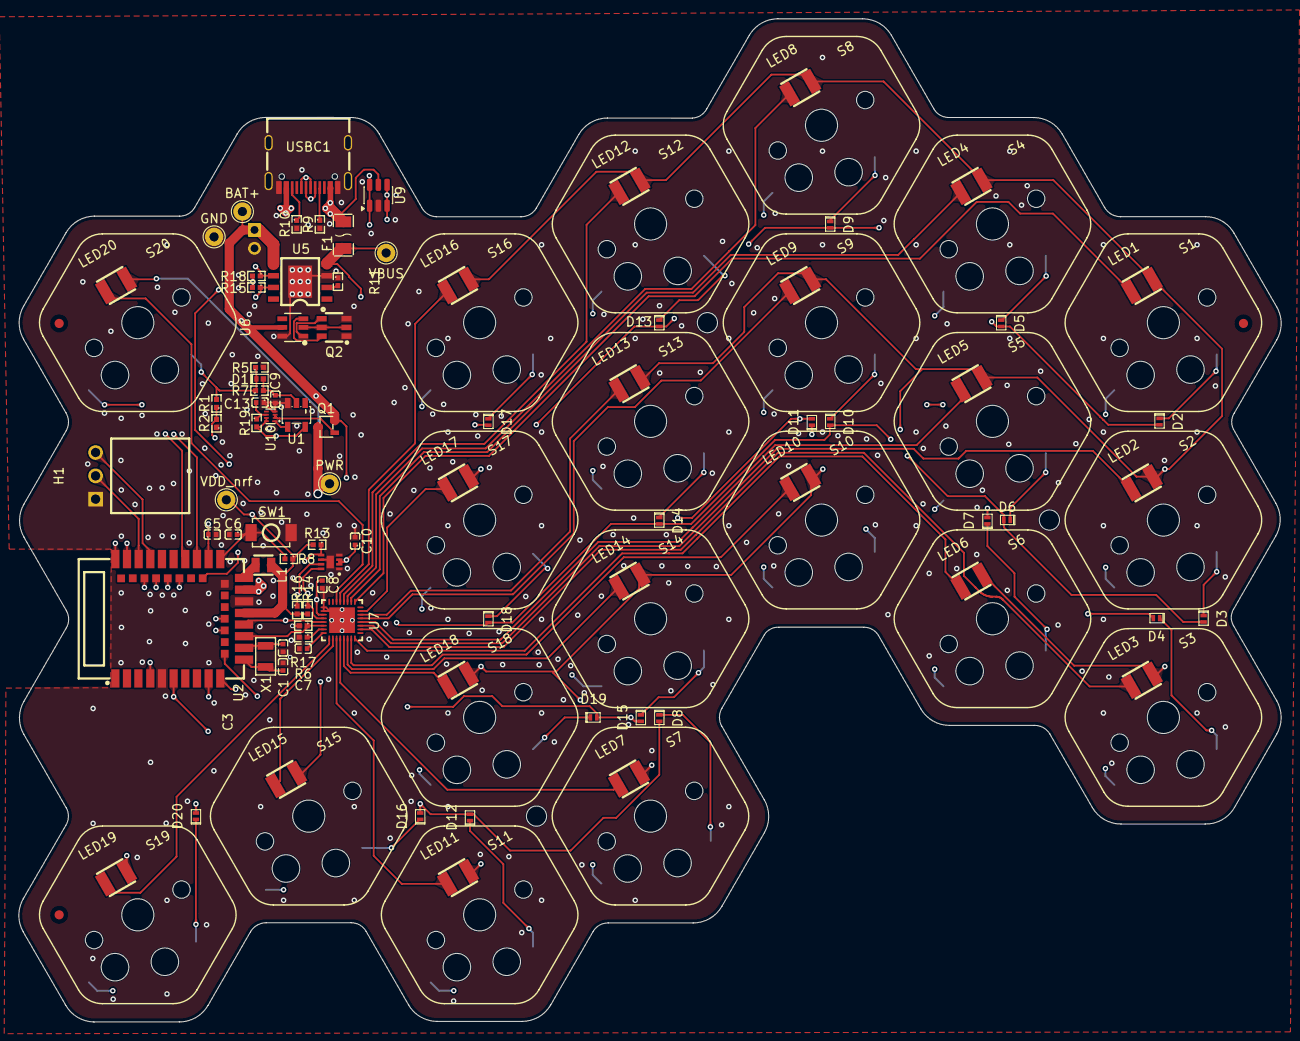
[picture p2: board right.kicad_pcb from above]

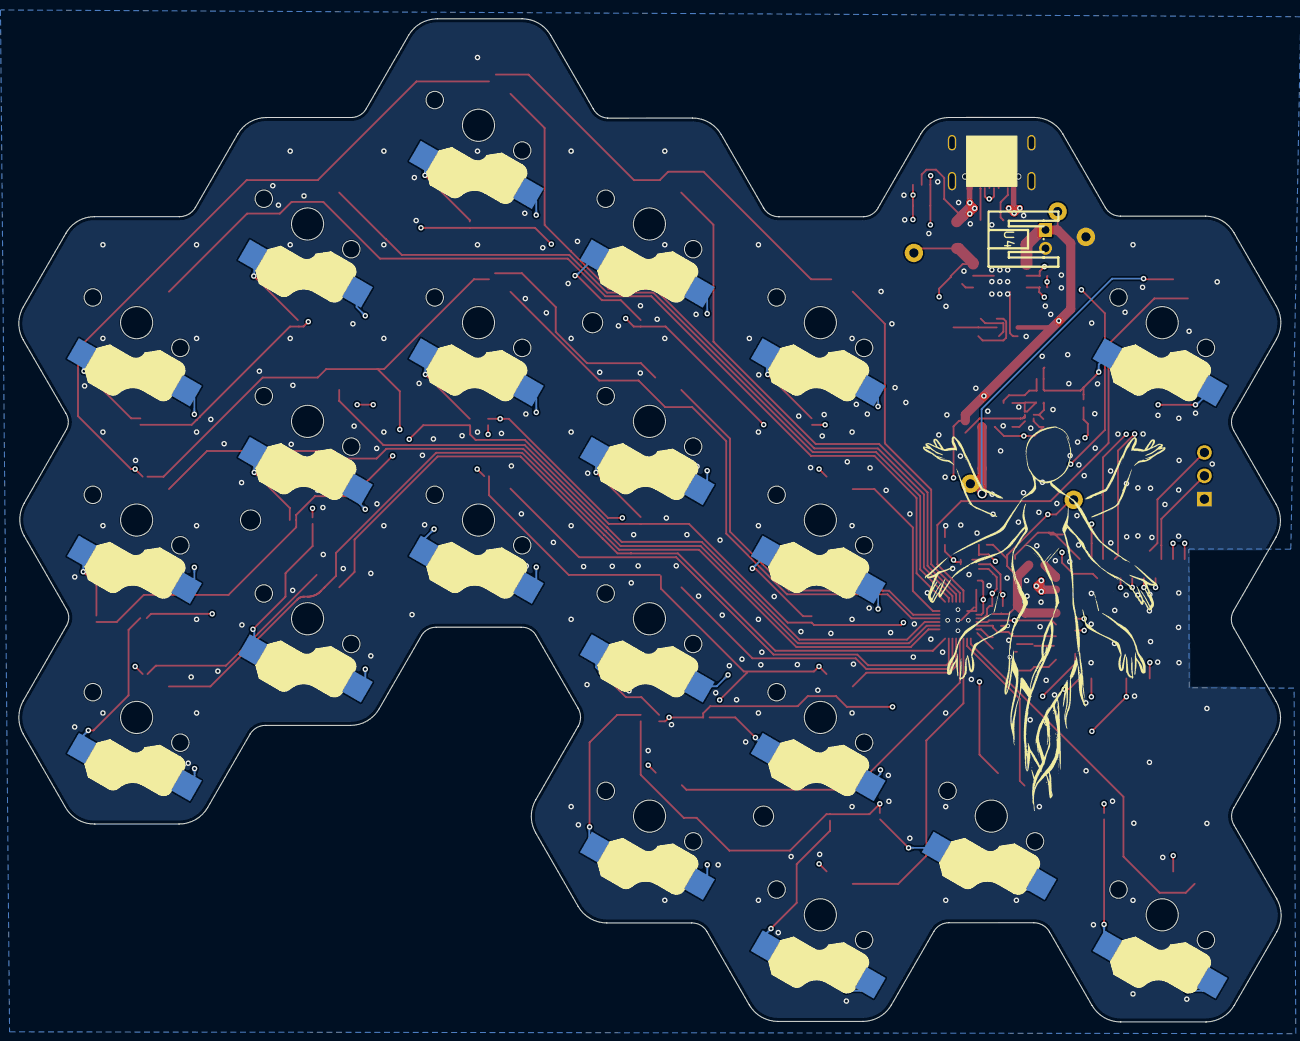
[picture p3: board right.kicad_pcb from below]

Board: 4 copper layers, 137.5 x 109.3 mm, 111 parts (22 on the bottom side), 82 nets.

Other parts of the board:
BAT+: TestPoint_THTPad_D2.0mm_Drill1.0mm
Fi4, Fi5: Fiducial_1mm_Mask2mm
Fi6: Fiducial_1mm_Mask2mm
G**: LOGO; handy
GND: TestPoint_THTPad_D2.0mm_Drill1.0mm
PWR: TestPoint_THTPad_D2.0mm_Drill1.0mm
VBUS: TestPoint_THTPad_D2.0mm_Drill1.0mm
VDD_nrf: TestPoint_THTPad_D2.0mm_Drill1.0mm

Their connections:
/BAT+: BAT+.1; also elsewhere on the board
/PWR: PWR.1; also elsewhere on the board
/VBUS: VBUS.1; also elsewhere on the board
/VDD_nRF: VDD_nrf.1; also elsewhere on the board
GND: GND.1; also elsewhere on the board

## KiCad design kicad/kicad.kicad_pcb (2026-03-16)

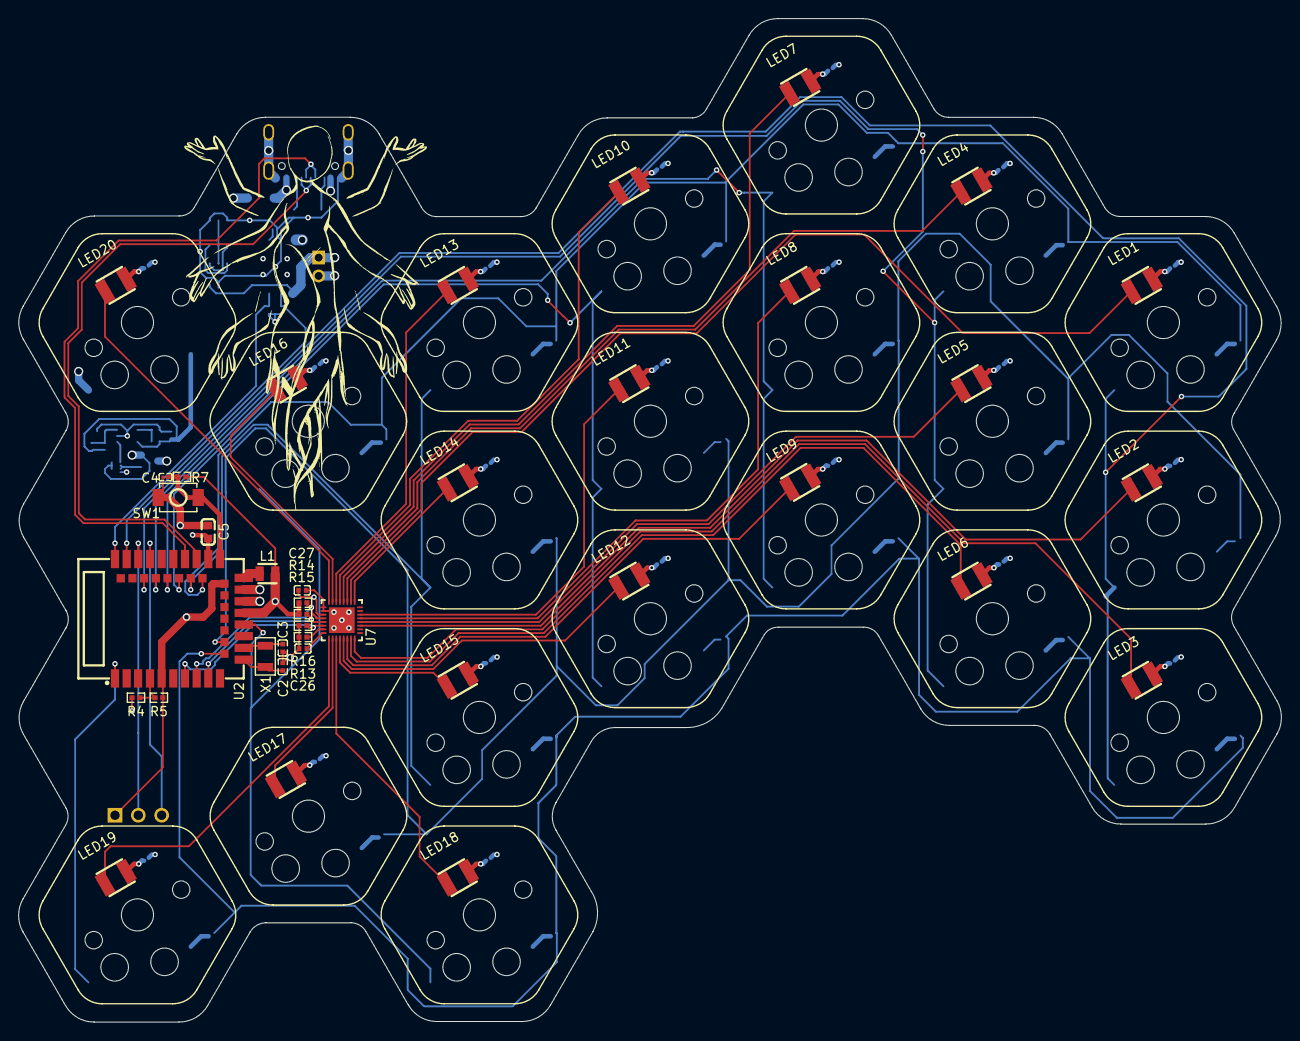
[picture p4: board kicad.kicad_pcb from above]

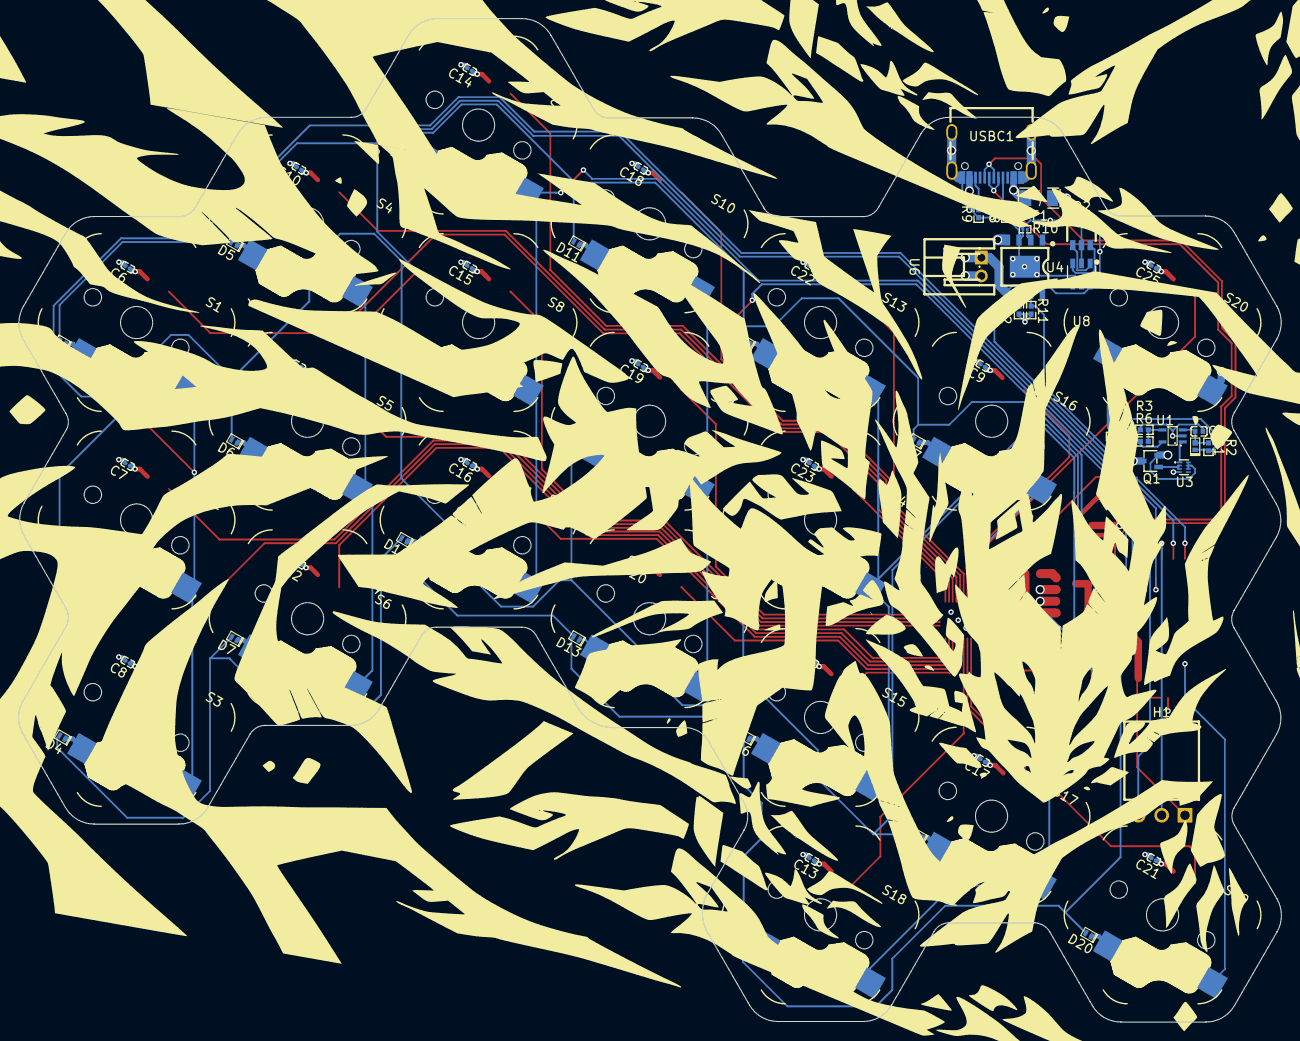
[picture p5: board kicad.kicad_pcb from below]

Board: 4 copper layers, 137.5 x 109.3 mm, 147 parts (91 on the bottom side), 82 nets.

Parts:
Battery?: 3500mAh LiPo
C1: GRM155Z71A105KE01D; C0402
C2, C3: 0402CG120F500NT; C0402
C4, C6, C7, C8, C9, C10, C11, C12, C13, C14, C15, C16, C17, C18, C19, C20, C21, C22, C23, C24, C25: GRM033C71C104KE14D; C0201
C5: GRM188C71C475KE21D; C0603
C26, C27: GRM155C71C105KE11D; C0402
D1: NSR05F20NXT5G; DSN2_L1.0-W0.6-RD
D2, D3, D4, D5, D6, D7, D8, D9, D10, D11, D12, D13, D14, D15, D16, D17, D18, D19, D20: CDSQC4148-HF; X1-DFN1006-2_L1.0-W0.6-RD
F1: SMD1206-150C-16V; F1206
G**: LOGO; handy
H1: HC-PM254-8.5H-1X3PW; HDR-TH_3P-P2.54_HC-PM254-8.5H-1X3PW
L1: BRC2016T100K; IND-SMD_L2.0-W1.6_BRC2016
LED1, LED2, LED3, LED4, LED5, LED6, LED7, LED8, LED9, LED10, LED11, LED12, LED13, LED14, LED15, LED16, LED17, LED18, LED19, LED20: OSO5PAS1C1A-1MA; LED-SMD_L3.2-W2.8-LS3.5-RD-BLUE
Q1: PMF170XP,115; SOT-323-3_L2.0-W1.3-P1.30-LS2.1-BR
Q2: FS8205A_C2830320; SOT-23-6_L2.9-W1.6-P0.95-LS2.8-BR
R1: RC0402FR-07100KL; R0402
R2, R5: WR04W2494FTL; R0402
R3: RC0402FR-074M3L; R0402
R4, R6, R16: RC0402FR-071ML; R0402
R7, R11, R12: RC0402FR-0710KL; R0402
R8, R9, R14, R15: RC0402FR-075K1L; R0402
R10: RC0201FR-07680RL; R0201
R13: RT0402BRD0737K4L; R0402
S1, S2, S3, S4, S5, S6, S7, S8, S9, S10, S11, S12, S12#2, S13, S14, S15, S16, S17, S18, S19, S20: Choc HEX; PG1350_hotswap
SW1: TS-1088-AR02016; SW-SMD_L3.9-W3.0-P4.45
U1: TLV7031QDCKRQ1; SC-70-5_L2.0-W1.3-P0.65-LS2.1-BR
U2: E73-2G4M08S1C; WIRELM-SMD_E73-2G4M08S1C
U3: SN74LVC1G74DQER; X2SON-8_L1.4-W1.0-P0.35-BL
U4: BL8573CS8TR; ESOP-8_L4.9-W3.9-P1.27-LS6.0-BL-EP
U6: S2B-PH-K-S(LF)(SN); CONN-TH_S2B-PH-K-S-LF-SN
U7: LP5024RSMR; VQFN-32_L4.0-W4.0-P0.40-TL-EP
U8: DW01A_C42380662; SOT-23-6_L2.9-W1.6-P0.95-LS2.9-BL
USBC1: TYPE-C-31-M-12; USB-C_SMD-TYPE-C-31-M-12_1
X1: FC-13532.768KHZ9PF20PPM; OSC-SMD_L3.2-W1.5
component_case_outline: PG1350_hotswap
component_case_outline#2, component_case_outline#3, component_case_outline#4, component_case_outline#5: PG1350_hotswap
component_safe_space: PG1350_hotswap
component_safe_space#2, component_safe_space#3: PG1350_hotswap
hex_edge: b9cf7df6-7b49-4194-bf11-16aaca528749
hex_edge#2, hex_edge#3, hex_edge#4, hex_edge#5, hex_edge#6, hex_edge#7, hex_edge#8, hex_edge#9, hex_edge#10, hex_edge#11, hex_edge#12, hex_edge#13, hex_edge#14, hex_edge#15, hex_edge#16, hex_edge#17: b9cf7df6-7b49-4194-bf11-16aaca528749
key_template: PG1350_hotswap

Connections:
/ADC: R4.1, R5.2, U2.4 (AI4)
/BAT+: Q1.2 (S), S20.1, U3.6 (~CLR), U3.7 (~PRE), U3.8 (VCC), U4.5 (BAT), U6.1, U8.6 (VSS)
/CHRG: R11.1, U2.43 (NF2), U4.7 (CHRG)
/COL1: S1.1, S2.1, S3.1, U2.38 (P1.02)
/COL2: S4.1, S5.1, S6.1, U2.36 (P1.00)
/COL3: S7.1, S8.1, S9.1, U2.34 (P0.22)
/COL4: S10.1, S11.1, S12.1, U2.32 (P0.20)
/COL5: S13.1, S14.1, S15.1, U2.30 (P17)
/COL6: S16.1, S17.1, S18.1, U2.17 (P1.09)
/COL7: S19.1, U2.1 (P1.11)
/D+: U2.31 (D+), USBC1.A6 (DP1), USBC1.B6 (DP2)
/D-: U2.29 (D-), USBC1.A7 (DN1), USBC1.B7 (DN2)
/LED1: LED1.1, U7.18 (OUT17)
/LED2: LED2.1, U7.11 (OUT10)
/LED3: LED3.1, U7.8 (OUT7)
/LED4: LED4.1, U7.19 (OUT18)
/LED5: LED5.1, U7.12 (OUT11)
/LED6: LED6.1, U7.7 (OUT6)
/LED7: LED7.1, U7.20 (OUT19)
/LED8: LED8.1, U7.13 (OUT12)
/LED9: LED9.1, U7.6 (OUT5)
/LED10: LED10.1, U7.21 (OUT20)
/LED11: LED11.1, U7.14 (OUT13)
/LED12: LED12.1, U7.5 (OUT4)
/LED13: LED13.1, U7.22 (OUT21)
/LED14: LED14.1, U7.17 (OUT16)
/LED15: LED15.1, U7.4 (OUT3)
/LED16: LED16.1, U7.23 (OUT22)
/LED17: LED17.1, U7.2 (OUT1)
/LED18: LED18.1, U7.3 (OUT2)
/LED19: LED19.1, U7.1 (OUT0)
/LED20: LED20.1, U7.24 (OUT23)
/LED_EN: R16.1, U2.7 (AI0), U7.30 (EN)
/LED_SCL: R15.1, U2.9 (AI7), U7.29 (SCL)
/LED_SDA: R14.1, U2.8 (AI5), U7.28 (SDA)
/PMOS_gate: Q1.1 (G), U3.2 (D), U3.3 (~Q)
/PWR: C6.1, C7.1, C8.1, C9.1, C10.1, C11.1, C12.1, C13.1, C14.1, C15.1, C16.1, C17.1, C18.1, C19.1, C20.1, C21.1, C22.1, C23.1, C24.1, C25.1, C27.1, LED1.2, LED2.2, LED3.2, LED4.2, LED5.2, LED6.2, LED7.2, LED8.2, LED9.2, LED10.2, LED11.2, LED12.2, LED13.2, LED14.2, LED15.2, LED16.2, LED17.2, LED18.2, LED19.2, LED20.2, Q1.3 (D), R4.2, U2.23 (VDH), U7.27 (VCC)
/PWR_BTN: D1.1, R1.1, R2.1, R6.1, S20.2, U1.5 (VCC)
/RESET: C4.1, R7.2, SW1.1, U2.26 (RST)
/ROW1: D2.2, D5.2, D8.2, D11.2, D14.2, D17.2, U2.28 (P15)
/ROW2: D3.2, D6.2, D9.2, D12.2, D15.2, D18.2, U2.14 (P0.06)
/ROW3: D4.2, D7.2, D10.2, D13.2, D16.2, D19.2, D20.2, U2.12 (P0.26)
/STDBY: R12.1, U2.41 (NF1), U4.6 (STDBY)
/SWBCLK: H1.2, U2.39 (SWC)
/SWDIO: H1.3, U2.37 (SWD)
/VBUS: C5.1, F1.2, U2.27 (VBS), U4.4 (VCC)
/VDD_nRF: L1.2, R7.1, R11.2, R12.2, R14.2, R15.2, U2.19 (VCC)
GND: C1.2, C2.2, C3.2, C4.2, C5.2, C6.2, C7.2, C8.2, C9.2, C10.2, C11.2, C12.2, C13.2, C14.2, C15.2, C16.2, C17.2, C18.2, C19.2, C20.2, C21.2, C22.2, C23.2, C24.2, C25.2, C26.2, C27.2, H1.1, Q2.1 (S1), Q2.3 (S2), R1.2, R3.2, R5.1, R8.2, R9.2, R10.1, R13.2, R16.2, SW1.2, U1.2 (VEE), U2.5 (GND), U2.21 (GND), U2.24 (GND), U3.4 (GND), U4.3 (GND), U4.9 (EP), U6.2, U7.25 (ADDR0), U7.26 (ADDR1), U7.33 (GND), U8.5 (VDD), USBC1.1 (EH), USBC1.2 (EH), USBC1.3 (EH), USBC1.4 (EH), USBC1.A1B12 (GND), USBC1.B1A12 (GND)
unnamed: D2.1, S1.2
unnamed: D3.1, S2.2
unnamed: D4.1, S3.2
unnamed: D5.1, S4.2
unnamed: D6.1, S5.2
unnamed: D7.1, S6.2
unnamed: D8.1, S7.2
unnamed: D9.1, S8.2
unnamed: D10.1, S9.2
unnamed: D11.1, S10.2
unnamed: D12.1, S11.2
unnamed: D13.1, S12.2
unnamed: D14.1, S13.2
unnamed: D15.1, S14.2
unnamed: D16.1, S15.2
unnamed: D17.1, S16.2
unnamed: D18.1, S17.2
unnamed: D19.1, S18.2
unnamed: D20.1, S19.2
unnamed: F1.1, USBC1.A4B9 (VBUS), USBC1.B4A9 (VBUS)
unnamed: Q2.6 (G1), U8.3 (CO)
unnamed: Q2.4 (G2), U8.1 (DO)
unnamed: C1.1, D1.2, R2.2, U1.3 (IN+)
unnamed: R3.1, R6.2, U1.4 (IN-)
unnamed: U1.1 (OUT), U3.1 (CLK)
unnamed: L1.1, U2.25 (DCH)
unnamed: C2.1, U2.11 (XL1), X1.1
unnamed: C3.1, U2.13 (XL2), X1.2
unnamed: R10.2, U4.2 (PROG)
unnamed: R13.1, U7.31 (IREF)
unnamed: C26.1, U7.32 (VCAP)
unnamed: Q2.2 (D1/D2), Q2.5 (D1/D2), U8.2 (VM)
unnamed: R8.1, USBC1.A5 (CC1)
unnamed: R9.1, USBC1.B5 (CC2)

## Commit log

2026-03-06 git init
    [board.dxf, combo.dxf, combo_keys_thumb.dxf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]
2026-03-08 a lot... almost done schematic... need to rewire to new mcu module... pcb key/led/diode placement done... other componenets tbd
    [board.dxf, combo.dxf, combo_keys_thumb.dxf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]
2026-03-09 changed raw mcu to e73module with antena... cleaned pcb a little
    [kicad.kicad_pcb, kicad.kicad_sch, nrf52840_populated.kicad_sch]
2026-03-10 kicad-backups folder removed
    [kicad.kicad_pcb]
2026-03-10 psb outline
    [kicad.kicad_pcb, kicad.kicad_sch]
2026-03-12 ... started doing wiring
    [kicad.kicad_pcb, kicad.kicad_sch]
2026-03-13 finished part placement and wiring. TODO: wire swd pins. mirror the board for left side.
    [bom.csv, designators.csv, kicad.kicad_pcb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]
2026-03-16 added art... and some other stuff
    [kicad.kicad_pcb, kicad.kicad_sch]
2026-03-16 added fiducials
    [right.kicad_pcb, right.kicad_sch]
2026-03-17 added mounting holes
    [right.kicad_pcb]
2026-03-17 changed mounting holes. cleared a little bit, created 21 key version... needs 21 key integration
    [right.kicad_pcb, right21.kicad_pcb, right21.kicad_sch]
2026-03-17 removed 21.... instead ill just move the high index to bottom index
    [right21.kicad_pcb, right21.kicad_sch]
2026-03-18 integrated the move from distant index to lowest index... changed from 7colX3row to 5colX4row
    [right.kicad_pcb, right.kicad_sch]
2026-03-18 finished right, i hope
    [left.kicad_pcb, right.kicad_pcb]
2026-03-19 started left
    [left.kicad_pcb, right.kicad_pcb]
2026-03-19 moved one mounting hole
    [left.kicad_pcb, right.kicad_pcb]
2026-04-10 left wiring done... right changed to shmitt inctead of comparator... need to do same on left... fixing of right in progress
    [left.kicad_pcb, left.kicad_sch, right.kicad_pcb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]
2026-04-12 pcb done. schematick done. need to double check schematick and ask in discord about pcb... but else done
    [left.kicad_pcb, left.kicad_sch, right.kicad_pcb]
2026-04-12 text position changes
    [left.kicad_pcb, left.kicad_sch, right.kicad_pcb]
2026-04-12 checked and update schematics on off need to update it in pcb...
    [left.kicad_sch, right.kicad_sch]
2026-04-13 started redesign... removed led caps and moved everything to fron layer... need to move debug connector to front and than try to change pcb stack.
    [right.kicad_pcb, right.kicad_sch]
2026-05-02 finished. needes inspection. added battery measurer. wired left side
    [left.kicad_pcb, left.kicad_sch, right.kicad_pcb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]
2026-05-03 changed on/off timing resistor to 2M61 0805
    [left.kicad_pcb, left.kicad_sch, right.kicad_pcb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]
2026-05-04 added gnd vias all over the board. went trough schematic again. changed resistor for rc to bigger one in footprint, and smaller one in Ohm. both left and right sides are ready. just need to go over t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
    [left.kicad_pcb, left.kicad_sch, right.kicad_pcb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]
2026-05-11 update vias under led controller... on left part. checking correctness of footprints in progress
    [left.kicad_pcb, reader_bom.csv]
2026-05-11 change vias under led controller on right side
    [right.kicad_pcb]
2026-05-11 checked most component footprints
    [left.kicad_pcb, right.kicad_pcb]
2026-05-11 checked and updated all major components
    [left.kicad_pcb, right.kicad_pcb]
2026-06-21 both sides done. changed few components for their basic or more affordable alternaatives.
    [bom.csv, designators.csv, left.csv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]
2026-06-27 first panelization... changing parts because of availability
    [left.kicad_pcb, left.kicad_sch, panel.kicad_pcb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]
2026-06-29 ... todo: update panel woth newest left and right pcb
    [left.kicad_pcb, left.kicad_sch, panel.kicad_pcb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]
2026-06-29 added lcsc part # for USBLC6-2SC6
    [left.kicad_sch, right.kicad_sch]
2026-06-29 added readme, design, licenses
    [bom.csv, demo.dxf, demo.kicad_pcb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]
2026-07-07 clearing pcbs for panelisation
    [left.kicad_pcb, left_bom.csv, left_designators.csv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]

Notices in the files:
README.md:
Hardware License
